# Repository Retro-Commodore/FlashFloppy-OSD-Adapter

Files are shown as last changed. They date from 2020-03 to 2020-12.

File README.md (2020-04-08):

# FlashFloppy-OSD-Adapter
 Adapter which should make it a little easier to handle the bluepill for regular GOTEK drives for the Amiga
 
# What is it?
It's just a basic adapter which draws out the pins needed to connect the bluepill with the Amiga and GOTEK drive.
You can also program the Bluepill using this adapter. 
 
# How to use
Download the gerber (zip) file and upload it to your favorite PCB manufacturer. I'm using jlcpcb.com.

Check out this image and use the link below for reference
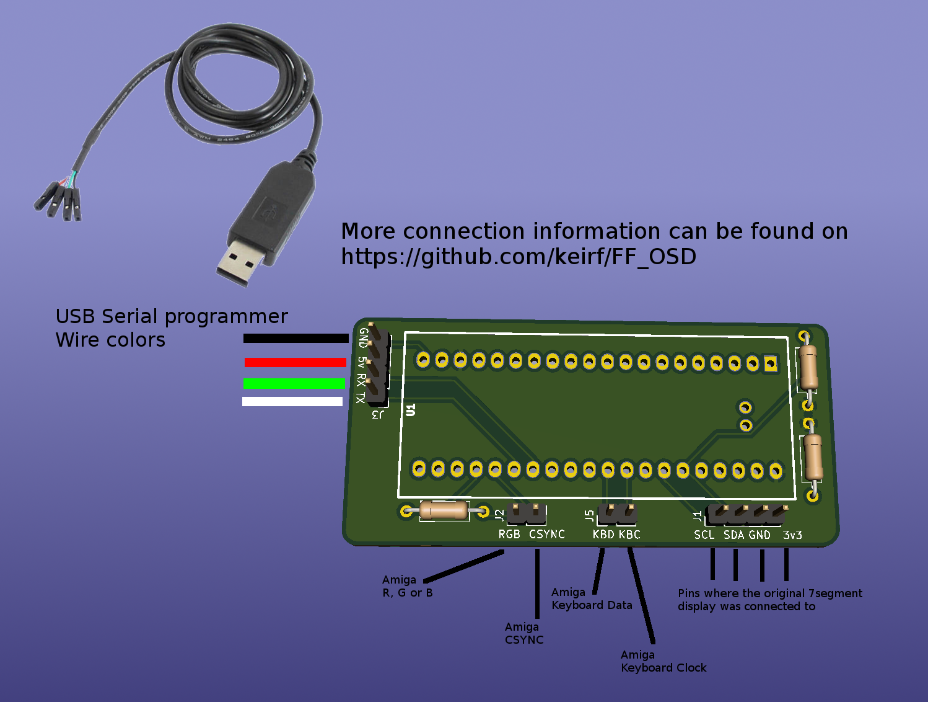
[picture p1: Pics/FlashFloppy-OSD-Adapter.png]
FF-OSD-Adapter


Go to https://github.com/keirf/FF_OSD 

You decide if you want to use sil headers or just solder wires to the holes.
If you have a 3D Printet drive bay, you can attach the Adapter with Bluepill to here.

# Do I really need this?
No, you can use the Bluepill without this adapter.

# More?
You can isolate the bottom, with i.e. cardboard/hotglue, or isolation tape, to prevent accidently shorts.

# Placements
The resistor values are printet on the silkscreen, which isn't visible on the picture above.
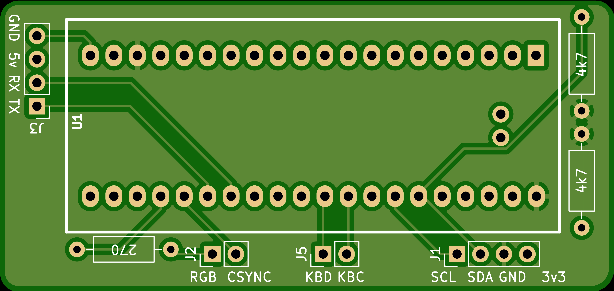
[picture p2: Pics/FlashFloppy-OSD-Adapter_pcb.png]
FF-OSD-Adapter


# Parts list
2 x 4,7k Ohm throughhole resistor

1 x 270  Ohm throughhole resistor

2 x 1x4 pin SIL header male - you can ommit these if you want to solder wires directly and program before installing

2 x 1x2 pin SIL header male - you can ommit these if you want to solder wires directly

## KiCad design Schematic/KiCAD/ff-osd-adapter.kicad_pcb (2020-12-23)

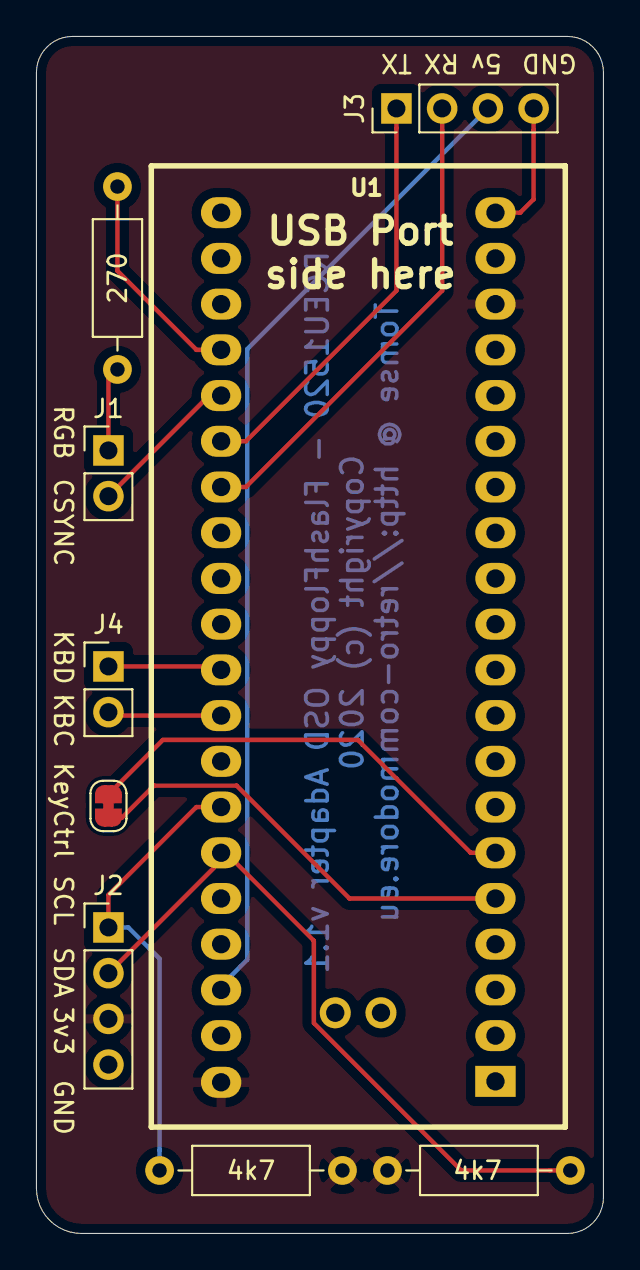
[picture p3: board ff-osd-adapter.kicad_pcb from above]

Board: 2 copper layers, 31.5 x 66.5 mm, 9 parts (0 on the bottom side), 14 nets.

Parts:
J1: Amiga_Video; PinHeader_1x02_P2.54mm_Vertical
J2: GOTEK; PinHeader_1x04_P2.54mm_Vertical
J3: Programming; PinHeader_1x04_P2.54mm_Vertical
J4: Amiga_Keyboard; PinHeader_1x02_P2.54mm_Vertical
KeyCtrl: Amiga_Key_Input_To_FF; SolderJumper-2_P1.3mm_Bridged_RoundedPad1.0x1.5mm
R1: 270; R_Axial_DIN0207_L6.3mm_D2.5mm_P10.16mm_Horizontal
R2, R3: 4k7; R_Axial_DIN0207_L6.3mm_D2.5mm_P10.16mm_Horizontal
U1: BluePill_STM32F103C

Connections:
+3V3: J2.3, R2.1, R3.1, U1.18, U1.40
/5v: J3.3, U1.38
/CSYNC: J1.2, U1.25
/KB_CLOCK: J4.2, U1.32
/KB_DATA: J4.1, U1.31
/RGB: J1.1, R1.1
/RX: J3.2, U1.27
/SCL: J2.1, R3.2, U1.34
/SDA: J2.2, R2.2, U1.35
/TX: J3.1, U1.26
GND: J2.4, J3.4, U1.19, U1.20, U1.39
unnamed: KeyCtrl.1, U1.5
unnamed: KeyCtrl.2, U1.6
unnamed: R1.2, U1.24

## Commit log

2020-03-16 Initial release
    Version 1.0 of the FlashFloppy adapter
    [ff-osd-adapter.kicad_pcb, ff-osd-adapter.sch]
2020-03-16 Create FlashFloppy-OSD-Adapter.png
    Added pcb image
2020-03-17 Create FlashFloppy-OSD-Adapter_pcb.png
    adding pcb image for documentation
2020-04-06 Cosmetic Changes
    [ff-osd-adapter.kicad_pcb, ff-osd-adapter.sch]
2020-12-23 Cosmetic changes/corrections
    [ff-osd-adapter.kicad_pcb]
2020-12-23 v1.1 - added support for Amiga Keyboard disk change control
    [ff-osd-adapter.kicad_pcb, ff-osd-adapter.sch]

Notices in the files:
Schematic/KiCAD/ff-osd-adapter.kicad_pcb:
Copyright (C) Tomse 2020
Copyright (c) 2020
